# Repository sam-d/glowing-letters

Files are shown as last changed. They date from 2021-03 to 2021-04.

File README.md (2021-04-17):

# Glowing letters, controlled by an Arduino and activated with a PIR motion sensor

This project shows how to combine 3D printing and electronics to create
illuminated letters that fade through a 'sunrise' color palette. If you happen
to have the same initials, feel free to print the STL files from the 'models'
directory. I used 58 LEDS from a 30 LEDS per meter strip.

If you have different initials, the OpenSCAD source in folder 'openscad' should
provide inspiration and should be easy to adapt.

# BOM

* WS811 LED strips, 30 LEDS per meter, 2 meters
* PIR motion sensor (I used a module of type HC-SR501
* Arduino nano 
* cables (I used 0,16 mm2 in 3 colors black, red, white)
* 5V power adapter with wall mart. It should be rated above 3 ampere. I used
  5V/3A, and the LEDs are never white and not run at full brightness. Beware to
calculate power draw yourself when adapting this project
* barrel jack to fit the 5V power adapter
* soldering iron and solder

# Build Log

Build log can be found on [my blog](http://sam-d.com/blog/glowing-letters/)

# License

The code is under the [GPLv3 license](https://www.gnu.org/licenses/gpl-3.0.en.html), the designs and description are [CC-BY](https://creativecommons.org/licenses/by/4.0/)

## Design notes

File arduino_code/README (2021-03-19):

#Note

You will need to FastLED library installed to compile the code.

Please make sure to change the NUM_LEDS variable to the number of LEDs in your particular project. Also adapt the pin that controls the LEDs and the pin the controls the PIR sensor when using different pins.

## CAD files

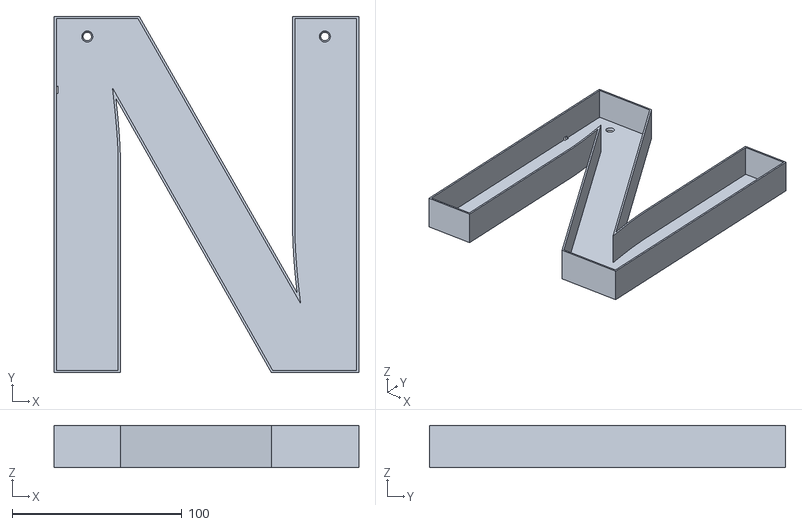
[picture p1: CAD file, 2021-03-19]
models/N_bottom_v4.stl
179.6 x 209.8 x 25.0

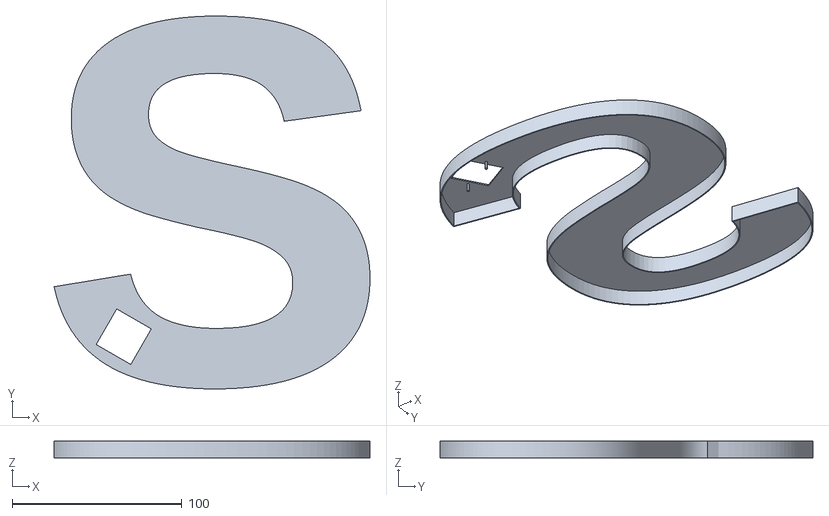
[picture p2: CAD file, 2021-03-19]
models/S_diffuser_v4.stl
186.0 x 219.5 x 10.0

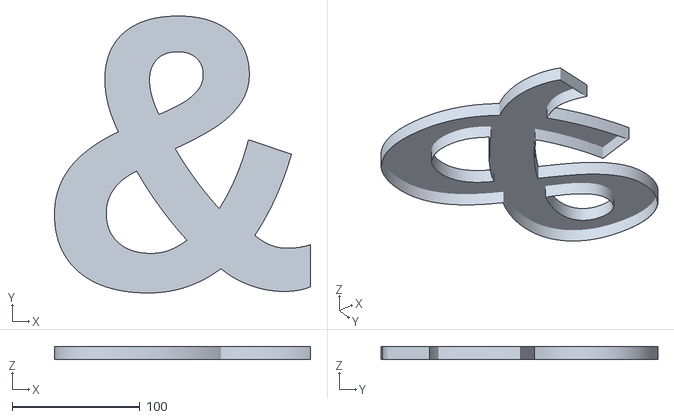
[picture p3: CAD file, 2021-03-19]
models/amp_diffuser_v4.stl
200.3 x 216.7 x 10.0

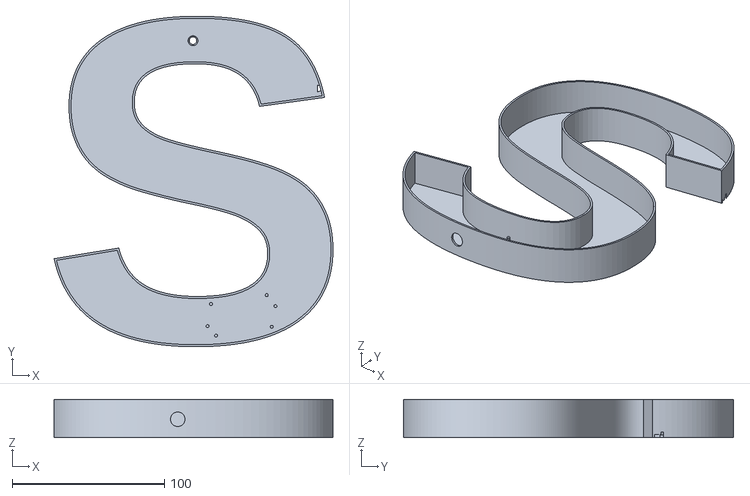
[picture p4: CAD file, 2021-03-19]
models/S_bottom_v4.stl
183.1 x 216.8 x 25.0

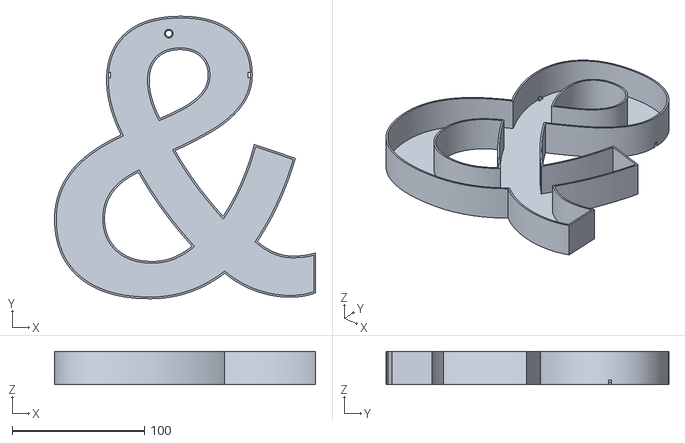
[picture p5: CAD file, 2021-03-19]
models/amp_bottom_v4.stl
197.7 x 214.0 x 25.0

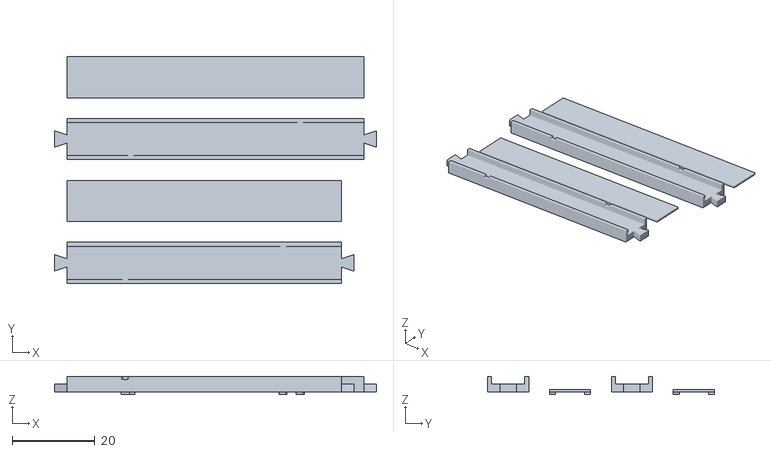
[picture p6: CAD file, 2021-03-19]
models/bridges_v4.stl
78.0 x 55.0 x 4.40

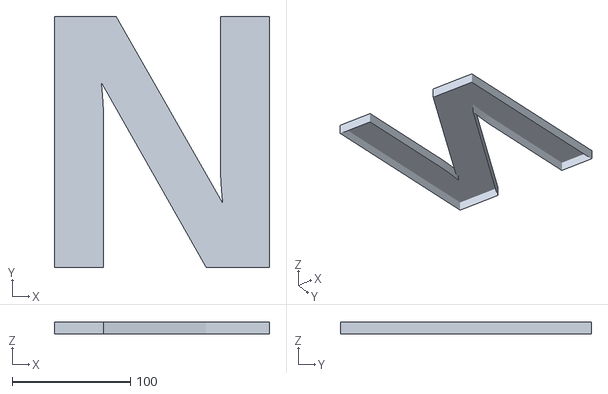
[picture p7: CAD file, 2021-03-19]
models/N_diffuser_v4.stl
182.3 x 212.4 x 10.0

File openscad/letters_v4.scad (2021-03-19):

$fn=100;
plate_thickness=1.6;
body_wall_thickness=2; //thickness of walls in mm
wall_thickness = 0.06; //thickness of the letter walls as delta offset.
letter_depth=25;//50;
support_height=25;
diffuser_thickness=0.8;
diffuser_border=10;
tol=0.12; //tolerance in percent
pin_height=2; //height of pins used in pin_mask and neg_pin_mask
module letters(){
scale([22,22,1]) linear_extrude(letter_depth) text("S&N", font = "Liberation Sans:style=Bold");
}
module N_shell(){
    scale([22,22,1]) union(){
    linear_extrude(plate_thickness) text("N", font = "Liberation Sans:style=Bold");
    linear_extrude(letter_depth) difference(){
    text("N", font = "Liberation Sans:style=Bold");
    offset(delta=-wall_thickness) text("N", font = "Liberation Sans:style=Bold");
}}}

module S_shell(){
    scale([22,22,1]) union(){
    linear_extrude(plate_thickness) text("S", font = "Liberation Sans:style=Bold");
    linear_extrude(letter_depth) difference(){
    text("S", font = "Liberation Sans:style=Bold");
    offset(delta=-wall_thickness) text("S", font = "Liberation Sans:style=Bold");
}}}

module amp_shell(){
    scale([22,22,1]) union(){
    linear_extrude(plate_thickness) text("&", font = "Liberation Sans:style=Bold");
    linear_extrude(letter_depth) difference(){
    text("&", font = "Liberation Sans:style=Bold");
    offset(delta=-wall_thickness) text("&", font = "Liberation Sans:style=Bold");
}}}
   

module screw(){
    //translating to y=198 inside this odule ensures same height in all letters
    translate([0,198,2.1]) rotate([180,0,0]) cylinder(d1=7,d2=3,h=4);
}

module corner_bracket_arduino(h=7.5){
    union(){
//        cube([43,19,15]);
        //cube();
    translate([3,-1,0]) cylinder(r=1,h=h);
    translate([3,20,0]) cylinder(r=1,h=h);
    translate([40,-1,0]) cylinder(r=1,h=h);
    translate([40,20,0]) cylinder(r=1,h=h);
        translate([44.5,12,0]) cylinder(r=1,h=h);
        translate([-1.5,6,0]) cylinder(r=1,h=h);
    }
}

module plug(){
    rotate([-90,0,0])cylinder(d=9.5,h=20);
}

//S shell with all holes and utilities
module S_bottom_final(){
//screw hole
union(){
    difference(){
    S_shell();
    translate([100,0,0])screw();
    translate([90,-5,12]) plug();
    translate([185,161,0]) difference(){
        cable_bridge(66.5,dove_scale=1+tol,z_scale=1.8);
        cube([2,1,10]);
    }
}
    //arduino holder
color([1,0,0]) translate([112,5,body_wall_thickness-0.5]) rotate([0,0,9]) corner_bracket_arduino();

}}

module pir(){
   cube([23.5,24.2,10]);
}

module pir_pins(dia=1.8){
   //pir();
    union(){
        color([1,0,0]) translate([-2.8,12.1,-(5.5-diffuser_thickness)]) cylinder(d=dia,h=5.5);
        color([0,1,0]) translate([26,12.1,-(5.5-diffuser_thickness)]) cylinder(d=dia,h=5.5);
    }
}

module S_diffuser(){
    difference(){
        scale([22,22,1]) union(){
         color("blue")translate([0,0,diffuser_border-diffuser_thickness])      
            linear_extrude(diffuser_thickness) offset(delta=+wall_thickness/2) text("S", font = "Liberation Sans:style=Bold");
        
    linear_extrude(diffuser_border) difference(){
    offset(delta=+wall_thickness) text("S", font = "Liberation Sans:style=Bold");
    offset(delta=+wall_thickness/2)text("S", font = "Liberation Sans:style=Bold");
        }  
      }
      translate([32,22,1]) rotate([0,0,-30]) pir();  
 }
 translate([32,22,diffuser_border-diffuser_thickness]) rotate([0,0,-30]) pir_pins(dia=1.6);
 }


module cable_bridge(length,height=10,depth_channel=1.8,dove_scale=1,z_scale=1){
    difference(){
            union(){
                cube([length,height,body_wall_thickness]);
                translate([0,0,body_wall_thickness]) cube([length,1,depth_channel]);
                translate([0,height-1,body_wall_thickness]) cube([length,1,depth_channel]);
        //dovetails
                scale([dove_scale,dove_scale,z_scale]) dove_tail();
                translate([length,0,2*z_scale]) rotate([0,180,0]) scale([dove_scale,dove_scale,z_scale]) dove_tail();
            }
            translate([0,0,body_wall_thickness+0.5]) dt_mask(length);
    }
}

module cable_bridge_cap(length,height=10){
    union(){
        cube([length,height,0.6]);
        translate([0,0,-1.2]) dt_mask(length);
    }
}

module dt_mask(length){
    translate([length/4,1.5,0.6]) scale([0.5,0.5,0.5]) rotate([0,0,90]) dove_tail();
    translate([3*length/4,10-1.5,0.6]) scale([0.5,0.5,0.5]) rotate([0,0,-90]) dove_tail();
}
module dove_tail(){
linear_extrude(body_wall_thickness) polygon([[0,4],[0,6],[-3,7],[-3,3]]);
}


module amp_diffuser_old(){
    union(){
        scale([22,22,1]) linear_extrude(diffuser_thickness) text("&", font = "Liberation Sans:style=Bold");
        translate([0,0,-pin_height/2+diffuser_thickness]) amp_pin_mask();
    }
}

module amp_diffuser(){
    scale([22,22,1]) union(){
    color("blue")translate([0,0,diffuser_border-diffuser_thickness])linear_extrude(diffuser_thickness) offset(delta=+wall_thickness/2) text("&", font = "Liberation Sans:style=Bold");
    linear_extrude(diffuser_border) difference(){
    offset(delta=+wall_thickness) text("&", font = "Liberation Sans:style=Bold");
    offset(delta=+wall_thickness/2)text("&", font = "Liberation Sans:style=Bold");
}}}


module amp_bottom_final(){
    difference(){
        amp_shell();
        translate([100,0,0])screw();
        translate([-14,161,0])cable_bridge(66.5,dove_scale=1+tol,z_scale=1.8);
        translate([163.5,161,0])cable_bridge(72,dove_scale=1+tol,z_scale=1.8);
    }
}

module N_bottom_final(){
        difference(){
            N_shell();
            translate([40,0,0])screw();
            translate([180,0,0])screw();
            translate([-52.5,161,0])cable_bridge(72,dove_scale=1+tol,z_scale=1.8);
        }
}

module N_diffuser(){
    scale([22,22,1]) union(){
    color("blue")translate([0,0,diffuser_border-diffuser_thickness])linear_extrude(diffuser_thickness) offset(delta=+wall_thickness/2) text("N", font = "Liberation Sans:style=Bold");
    linear_extrude(diffuser_border) difference(){
    offset(delta=+wall_thickness) text("N", font = "Liberation Sans:style=Bold");
    offset(delta=+wall_thickness/2)text("N", font = "Liberation Sans:style=Bold");
}}}

viz();

module viz(){
    //%letters();
    translate([0,0,letter_depth+2]) S_diffuser();
    S_bottom_final();
    translate([185,161,0]) difference(){
    cable_bridge(66.5);
    cube([2,3.5,10]);
    }
    
    translate([185,161,5]) cable_bridge_cap(66.5);
    translate([199,0,0]) amp_bottom_final();
    translate([199,0,letter_depth+2]) amp_diffuser();
    translate([362.5,161,0])cable_bridge(72);
    translate([362.5,161,5]) cable_bridge_cap(72);
    translate([415,0,0]) N_bottom_final();
    translate([415,0,letter_depth+2]) N_diffuser();
}
////////////////////////////
//parts to generate STL for:
////////////////////////////
//S_diffuser();
//amp_diffuser();
//N_diffuser();
//S_bottom_final();
//amp_bottom_final();
//N_bottom_final();
//cable_bridge(66.5);//for the space between S, &
//translate([0,15,0])cable_bridge_cap(66.5);
//translate([0,30,0])cable_bridge(72); //for the space between &, N
//translate([0,45,0])cable_bridge_cap(72);

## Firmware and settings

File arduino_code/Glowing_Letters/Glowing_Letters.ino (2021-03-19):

#include <FastLED.h>

#define LED_PIN 5              // which pin are LEDS connected to?
#define NUM_LEDS 58			//TODO: Change this value
#define COLOR_ORDER GRB //RGB
#define LED_TYPE WS2811        // i'm using WS2811s, FastLED supports lots of different types.
#define BRIGHTNESS  200

//for the PIR sensor
const int sensor = 8; //which PIN the sensor is connected to
const int calibrationTime = 30;   
bool trigger = false;

//Palette related definitions
static uint8_t startIndex = 0;

struct CRGB leds[NUM_LEDS];
CRGBPalette16 gPal;
CRGBPalette16 currentPalette;
TBlendType    currentBlending;

// Gradient palette "Sunset_Real_gp", originally from
// http://soliton.vm.bytemark.co.uk/pub/cpt-city/nd/atmospheric/tn/Sunset_Real.png.index.html
// converted for FastLED with gammas (2.6, 2.2, 2.5)
// Size: 28 bytes of program space.

DEFINE_GRADIENT_PALETTE( Sunset_Real_gp ) {
  0, 120,  0,  0,
  22, 179, 22,  0,
  51, 255, 104,  0,
  85, 167, 22, 18,
  135, 100,  0, 103,
  198,  16,  0, 130,
  255,   0,  0, 160
};

void setup() {
  //setup PIR pin
  pinMode(sensor, INPUT);
  digitalWrite(sensor,LOW);
  delay(3000); // in case we do something stupid. We dont want to get locked out.

  FastLED.addLeds<LED_TYPE, LED_PIN, COLOR_ORDER>(leds, NUM_LEDS).setCorrection(TypicalLEDStrip);
  FastLED.setBrightness(BRIGHTNESS);
  gPal = CRGBPalette16( CRGB::Black, CRGB::OrangeRed, CRGB::Gold, CRGB::LightYellow);
  
   // Turn on all LEDs
  for(int i = 0; i < NUM_LEDS; i++) {
    // Set the i'th led to red to test all LEDs work 
    leds[i] = CRGB::Red;
  }     
  // Show the leds
  FastLED.show();
  delay(3000);
  FastLED.clearData();
  FastLED.show();
    
  //give the sensor some time to calibrate
  for(int i = 0; i < calibrationTime; i++){
    delay(1000);
  }
  delay(50);
}



void loop()
{
    if(digitalRead(sensor)==HIGH){ 
      trigger = true;
    }

    while(trigger){
      currentPalette = Sunset_Real_gp; 
      currentBlending = LINEARBLEND;
      if(reverse){
        startIndex -= 1;
      }else{
        startIndex += 1; // motion speed
      }
      FillLEDsFromPaletteColors(startIndex);
      FastLED.show();
      FastLED.delay(500); //speed of going through the palette

      if(digitalRead(sensor) == LOW){   
        trigger = false;
      }    
    }
    for(int i = 0; i < NUM_LEDS; i++) {
    // Set the i'th led to black 
      leds[i] = CRGB::Black;
      }
      FastLED.show();     
}


void FillLEDsFromPaletteColors( uint8_t colorIndex)
{ 
     for( int i = 0; i < NUM_LEDS; i++) {
        leds[i] = ColorFromPalette( currentPalette, colorIndex, BRIGHTNESS, currentBlending);
        colorIndex = colorIndex % 255;
     }
}
